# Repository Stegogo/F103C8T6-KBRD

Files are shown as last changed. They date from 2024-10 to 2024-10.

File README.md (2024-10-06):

# KBRD

4-key arrow keyoard from scratch, based on STM32F103C8T6. Work in progress.

<p align="center">
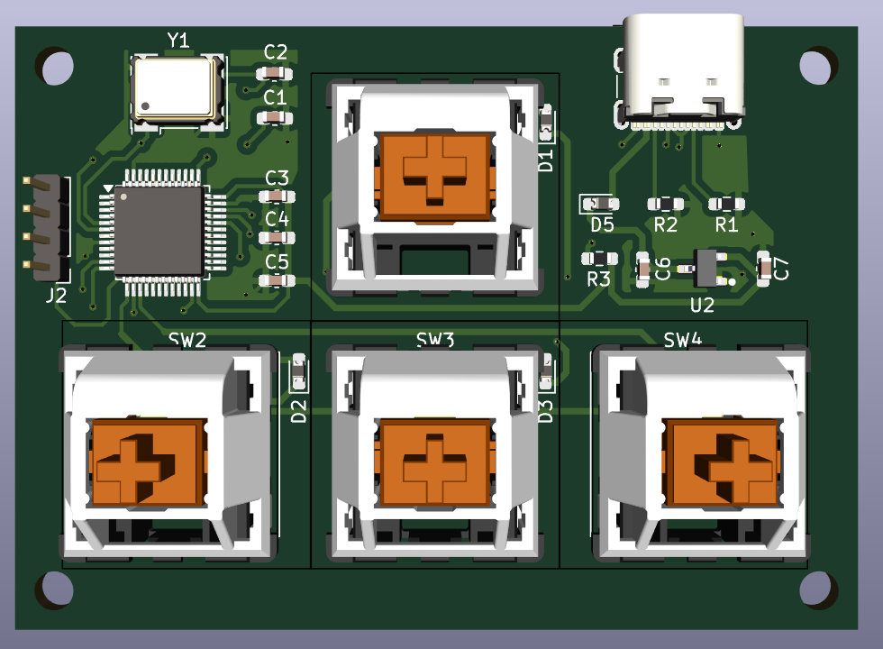
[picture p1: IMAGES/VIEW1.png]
3D View front
     
  </p>

## Scematic and PCB
  <p align="center">
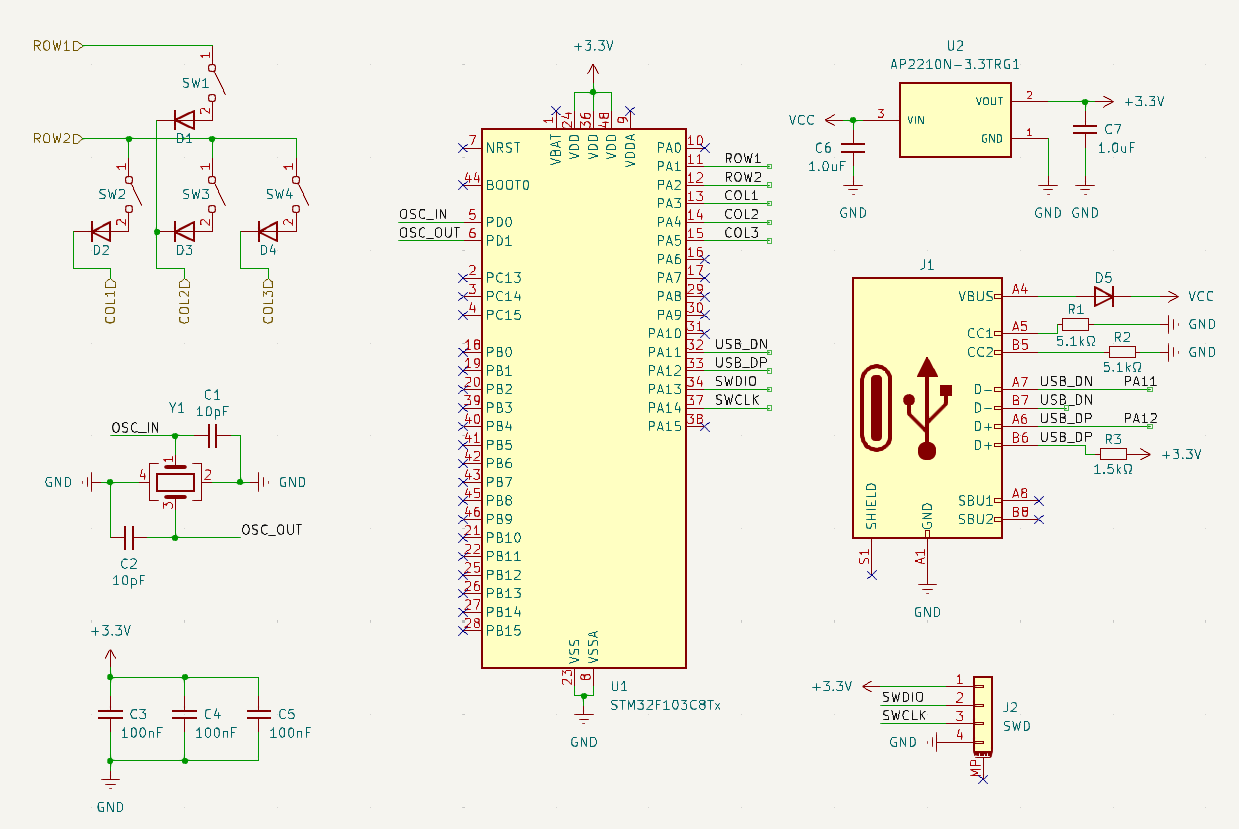
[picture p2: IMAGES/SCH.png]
Schematic
    
  </p>
   <p align="center">
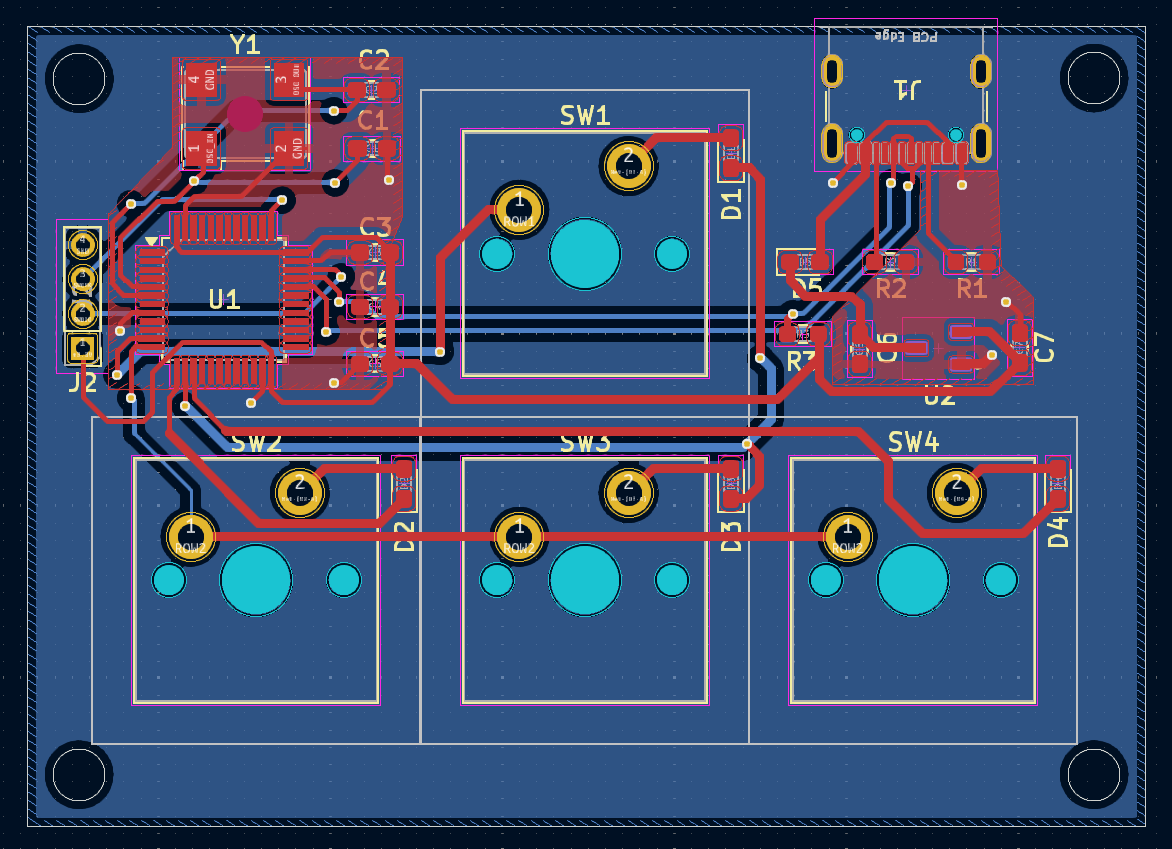
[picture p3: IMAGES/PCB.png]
PCB
    
  </p>

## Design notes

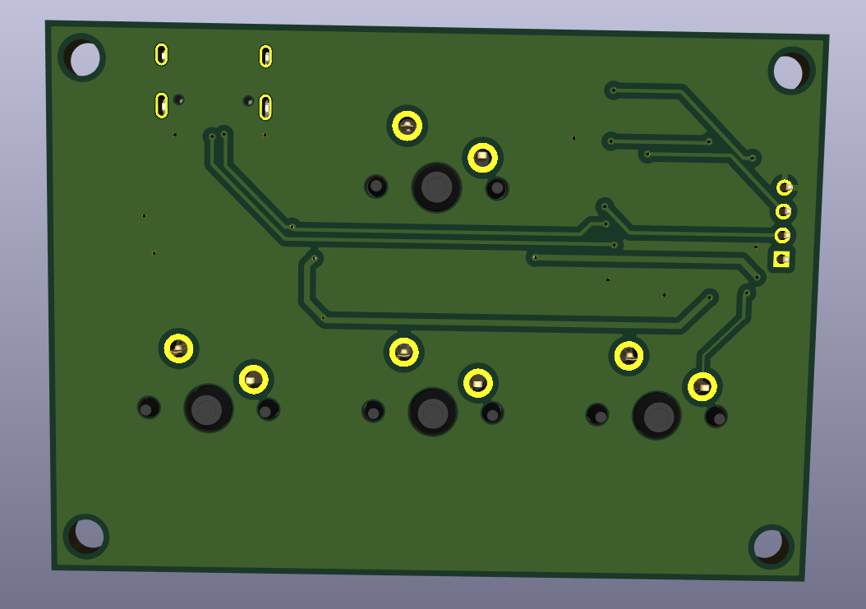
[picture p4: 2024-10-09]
IMAGES/VIEW3.png

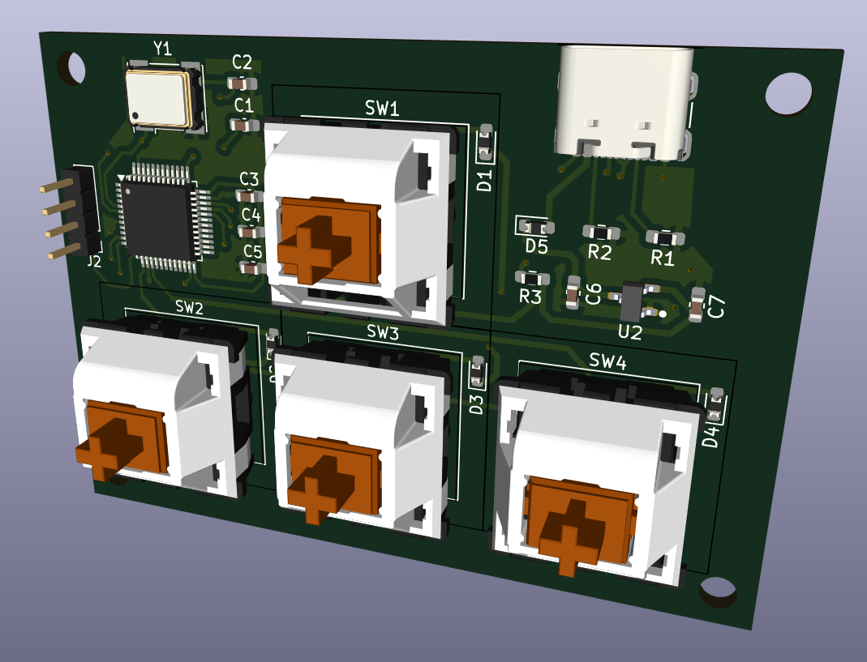
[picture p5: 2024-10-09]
IMAGES/VIEW2.png

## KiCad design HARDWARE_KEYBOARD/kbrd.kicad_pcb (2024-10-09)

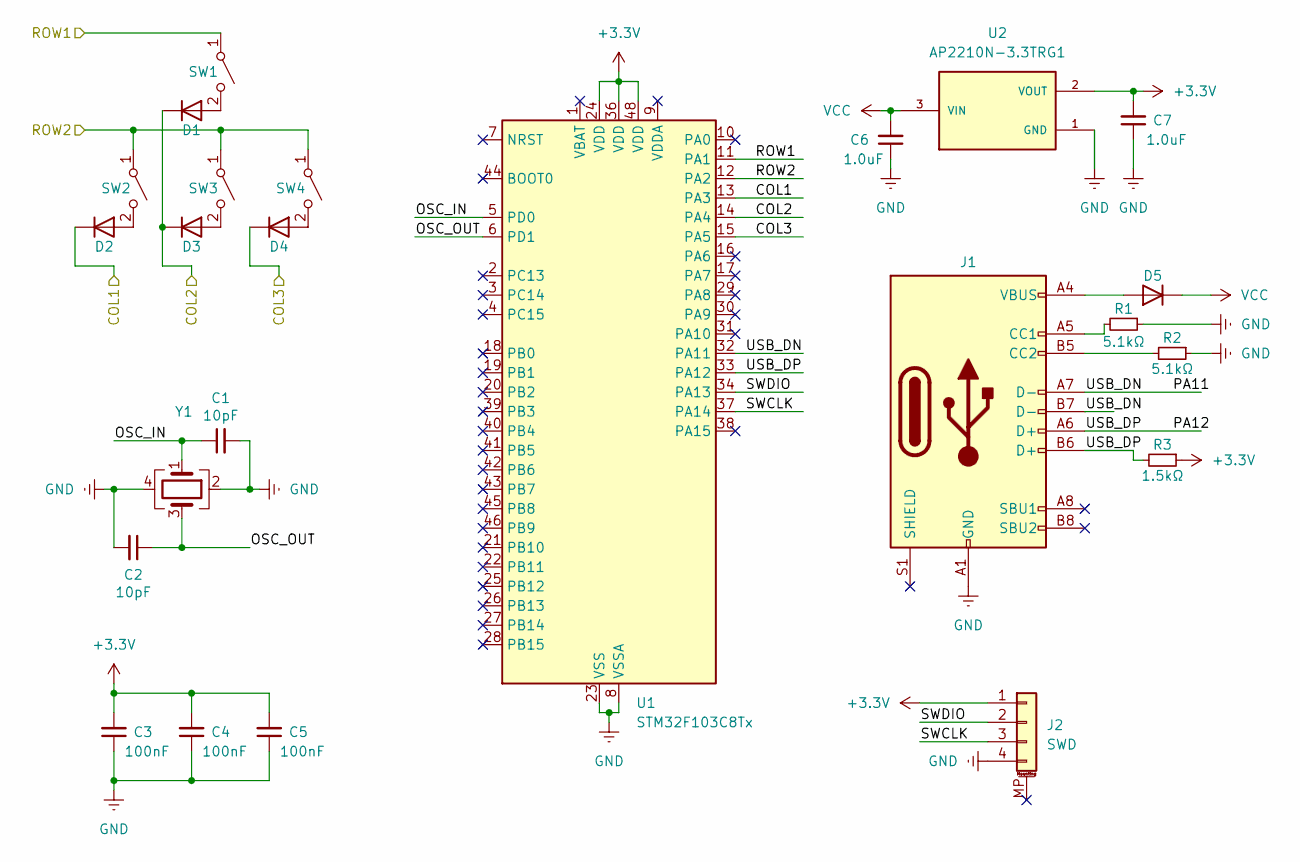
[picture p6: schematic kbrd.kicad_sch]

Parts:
C1, C2: 10pF; C_0603_1608Metric_Pad1.08x0.95mm_HandSolder
C3, C4, C5: 100nF; C_0603_1608Metric_Pad1.08x0.95mm_HandSolder
C6, C7: 1.0uF; C_0603_1608Metric_Pad1.08x0.95mm_HandSolder
D1, D2, D3, D4, D5: D; D_0603_1608Metric_Pad1.05x0.95mm_HandSolder
J1: USB_C_Receptacle_USB2.0_16P; USB_C_Receptacle_GCT_USB4105-xx-A_16P_TopMnt_Horizontal
J2: SWD; PinHeader_1x04_P2.00mm_Vertical
R1, R2: 5.1kΩ; R_0603_1608Metric_Pad0.98x0.95mm_HandSolder
R3: 1.5kΩ; R_0603_1608Metric_Pad0.98x0.95mm_HandSolder
SW1, SW2, SW3, SW4: SW_SPST; SW_Cherry_MX_PCB_1.00u
U1: STM32F103C8Tx; LQFP-48_7x7mm_P0.5mm
U2: AP2210N-3.3TRG1; SOT-23-3
Y1: Crystal_GND24; Oscillator_SMD_Abracon_ASV-4Pin_7.0x5.1mm

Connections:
+3.3V: C3.2, C4.2, C5.2, C7.2, J2.1, R3.1, U1.24 (VDD), U1.36 (VDD), U1.48 (VDD), U2.2 (VOUT)
/COL1: D2.1 (K), U1.13 (PA3)
/COL2: D1.1 (K), D3.1 (K), U1.14 (PA4)
/COL3: D4.1 (K), U1.15 (PA5)
/OSC_IN: C1.1, U1.5 (PD0), Y1.1
/OSC_OUT: C2.1, U1.6 (PD1), Y1.3
/PA11: J1.A7 (D-), J1.B7 (D-), U1.32 (PA11)
/PA12: J1.A6 (D+), J1.B6 (D+), R3.2, U1.33 (PA12)
/ROW1: SW1.1 (A), U1.11 (PA1)
/ROW2: SW2.1 (A), SW3.1 (A), SW4.1 (A), U1.12 (PA2)
/SWCLK: J2.3, U1.37 (PA14)
/SWDIO: J2.2, U1.34 (PA13)
GND: C1.2, C2.2, C3.1, C4.1, C5.1, C6.1, C7.1, J1.A1 (GND), J1.A12 (GND), J1.B1 (GND), J1.B12 (GND), J2.4, R1.1, R2.1, U1.8 (VSSA), U1.23 (VSS), U1.35 (VSS), U1.47 (VSS), U2.1 (GND), Y1.2, Y1.4
unnamed: D1.2 (A), SW1.2 (B)
unnamed: D2.2 (A), SW2.2 (B)
unnamed: D3.2 (A), SW3.2 (B)
unnamed: D4.2 (A), SW4.2 (B)
unnamed: D5.2 (A), J1.A4 (VBUS), J1.A9 (VBUS), J1.B4 (VBUS), J1.B9 (VBUS)
unnamed: J1.A5 (CC1), R1.2
unnamed: J1.B5 (CC2), R2.2
VCC: C6.2, D5.1 (K), U2.3 (VIN)

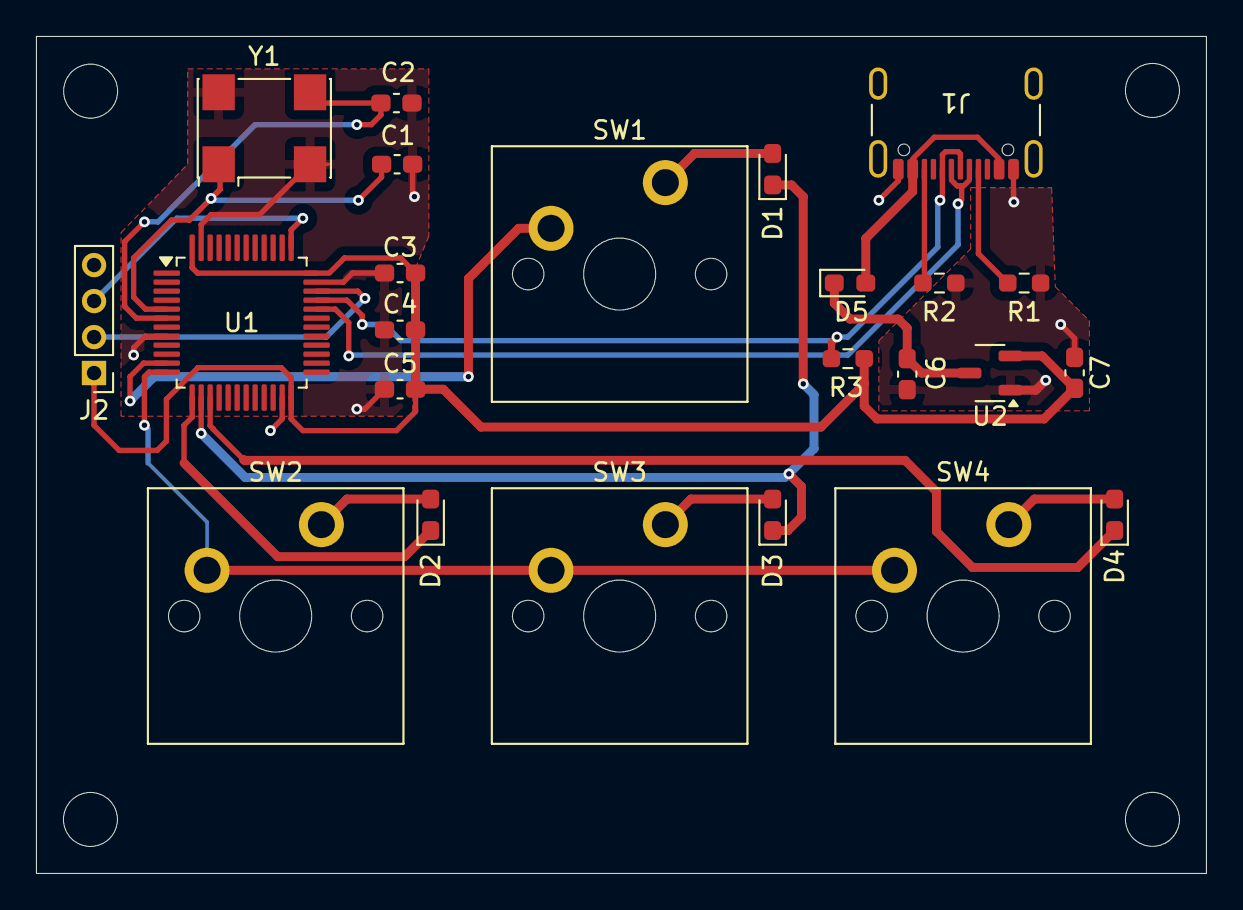
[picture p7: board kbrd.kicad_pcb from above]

Board: 2 copper layers, 65.0 x 46.5 mm, 24 parts (0 on the bottom side), 21 nets.

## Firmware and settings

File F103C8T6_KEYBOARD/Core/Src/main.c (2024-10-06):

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
/* Includes ------------------------------------------------------------------*/
#include "main.h"
#include "usb_device.h"

/* USER CODE BEGIN Includes */
#include "keyboard_action.h"
/* USER CODE END Includes */

extern TIM_HandleTypeDef htim2;

/* USER CODE BEGIN PV */
extern USBD_HandleTypeDef hUsbDeviceFS;
keyboardReportDesc HIDkeyboard  = {0,0,0,0,0,0,0,0};
uint16_t timer_200hz;
/* USER CODE END PV */

void SystemClock_Config(void);
static void MX_GPIO_Init(void);
static void MX_TIM2_Init(void);
/**
  * @brief  The application entry point.
  * @retval int
  */
int main(void)
{
  /* MCU Configuration--------------------------------------------------------*/

  /* Reset of all peripherals, Initializes the Flash interface and the Systick. */
  HAL_Init();

  /* Configure the system clock */
  SystemClock_Config();

  /* Initialize all configured peripherals */
  MX_GPIO_Init();
  MX_USB_DEVICE_Init();
  MX_TIM2_Init();
  /* USER CODE BEGIN 2 */
  HAL_TIM_Base_Start_IT(&htim2);
  /* USER CODE END 2 */

  /* Infinite loop */
  /* USER CODE BEGIN WHILE */
  while (1)
  {

    /* USER CODE END WHILE */

    /* USER CODE BEGIN 3 */
	  if (TIMER_COUNT == SET) {
		  TIMER_COUNT = RESET;
		  timer_200hz++;
		  if (timer_200hz == 2) {
			  poll_keyboard();
			  timer_200hz = 0;
		  }
	  }

  }
  /* USER CODE END 3 */
}

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
/* USER CODE BEGIN 4 */
void HAL_TIM_PeriodElapsedCallback(TIM_HandleTypeDef *htim)
{
//	if (htim->Instance == TIM2) {
//		// polling keyboard updates
//		poll_keyboard();
//	}
}
/* USER CODE END 4 */
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


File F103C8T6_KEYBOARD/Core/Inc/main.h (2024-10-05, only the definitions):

#define ROW1_Pin GPIO_PIN_1
#define ROW1_GPIO_Port GPIOA
#define ROW2_Pin GPIO_PIN_2
#define ROW2_GPIO_Port GPIOA
#define COL1_Pin GPIO_PIN_3
#define COL1_GPIO_Port GPIOA
#define COL2_Pin GPIO_PIN_4
#define COL2_GPIO_Port GPIOA
#define COL3_Pin GPIO_PIN_5
#define COL3_GPIO_Port GPIOA
#define LED_Pin GPIO_PIN_12
#define LED_GPIO_Port GPIOB
#define PORTA ((uint32_t *)((0x42000000  + ((0x40020014)-0x40000000)*32)))
#define PORTB ((uint32_t *)((0x42000000  + ((0x40020414)-0x40000000)*32)))
#define PORTC ((uint32_t *)((0x42000000  + ((0x40020814)-0x40000000)*32)))
#define PORTD ((uint32_t *)((0x42000000  + ((0x40020C14)-0x40000000)*32)))
#define PORTE ((uint32_t *)((0x42000000  + ((0x40021014)-0x40000000)*32)))
#define FLAG (*((volatile unsigned long*) 0x20001000))							//define  register with stated address
#define FLAG_BIT ((uint32_t *)((0x22000000  + ((0x20001000)-0x20000000)*32)))  //define bit register stated address
#define TIMER_COUNT				(FLAG_BIT[0])

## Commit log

2024-10-05 Init repo
    [kbrd.kicad_pcb, kbrd.kicad_sch]
2024-10-05 Fix firmware folder
    [F103C8T6_KEYBOARD Debug.cfg]
2024-10-06 Updated PCB & schematic
    [kbrd.kicad_pcb, kbrd.kicad_sch]
2024-10-08 Add copper zones; remove extra GND traces
    [kbrd.kicad_pcb]
2024-10-09 Change track sizes
2024-10-09 Add gerber
    [kbrd-B_Cu.gbr, kbrd-B_Mask.gbr, kbrd-B_Paste.gbr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]
2024-10-09 Chane volt regulator footprint to fit the one im going to use
    [kbrd.kicad_pcb, kbrd.kicad_sch]
2024-10-13 Add drill files
    [kbrd-NPTH.drl, kbrd-PTH.drl]

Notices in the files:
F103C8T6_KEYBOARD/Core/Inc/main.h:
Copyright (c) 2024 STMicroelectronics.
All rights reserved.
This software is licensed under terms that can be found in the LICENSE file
